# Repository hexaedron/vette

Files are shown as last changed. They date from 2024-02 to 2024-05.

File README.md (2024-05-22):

# vette

A diagnostic device to watch ECM parameters and errors from 1992 Chevy Corvette (LT1 engine) via ALDL interface.
Built with ch32v003 chip with sh1106 screen.

You will need [ch32v00fun](https://github.com/cnlohr/ch32v003fun/) and [fun_sh1106](https://github.com/hexaedron/fun_sh1106) to build it. I prefer using official WCH toolchain. If you prefer using vanilla risc-v GCC, then remove `#define WCH_FAST_INTERRUPT_ENABLED` from `cube_defs.h`.

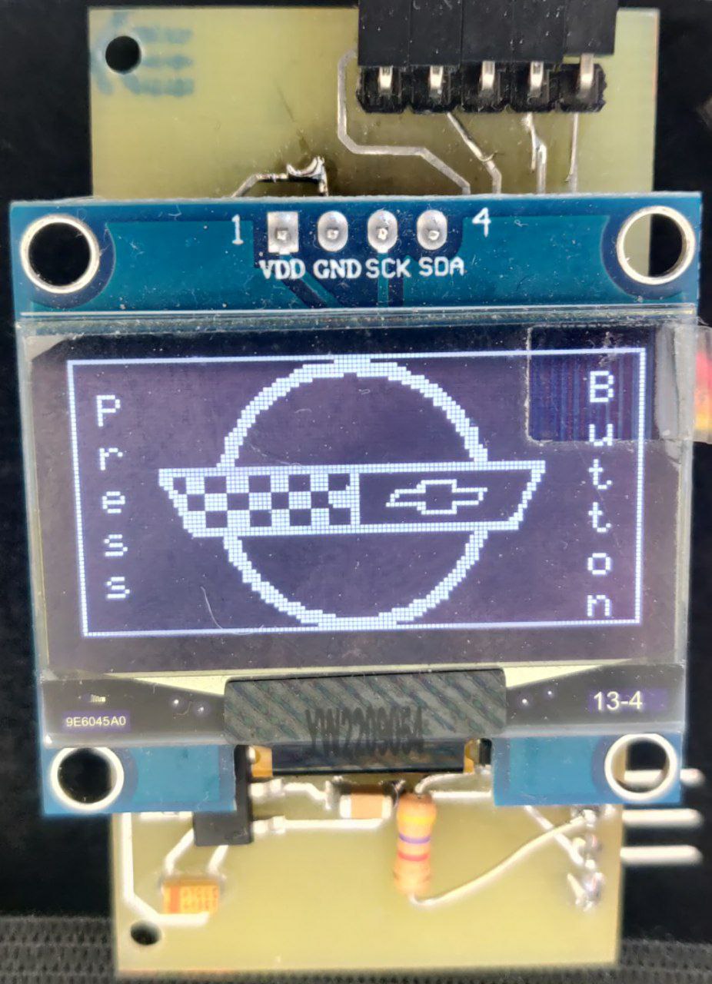
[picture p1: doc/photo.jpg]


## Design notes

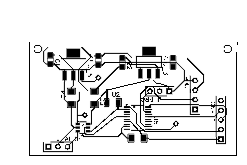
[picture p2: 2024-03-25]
PCB/PCB_PCB_CorvetteALDL_2024-03-25.png

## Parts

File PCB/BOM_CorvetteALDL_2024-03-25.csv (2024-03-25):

ID | Name | Designator | Footprint | Quantity | Manufacturer Part | Manufacturer | Supplier | Supplier Part | Price
1 | HDR-M-2.54_1x3 | J_PRG,J_ALDL | HDR-M-2.54_1X3 | 2 |  |  | LCSC | C180248 | 0.191
2 | HDR-M-2.54_1x5 | J_ENC | HDR-M-2.54_1X5 | 1 |  |  | LCSC | C358687 | 0.025
3 | 100nF | C3,C4,C5 | C1206 | 3 | C3216X7R2A104M160AA | TDK | LCSC | C3883507 | 0.477
4 | CH32V003F4P6 | U5 | TSSOP-20_L6.5-W4.4-P0.65-LS6.4-BL | 1 | CH32V003F4P6 | null | LCSC | C5187096 | 0.273
5 | LM1117GS-3.3 | U_3 | SOT-223-3_L6.5-W3.4-P2.30-LS7.0-BR | 1 | LM1117GS-3.3 | HTC | LCSC | C411821 | 0.154
6 | LM1117GS-5.0 | U_5 | SOT-223-3_L6.5-W3.4-P2.30-LS7.0-BR | 1 | LM1117GS-5.0 | HTC | LCSC | C465002 | 0.146
7 | 10uF | C1,C2,C6,C7 | CASE-A_3216 | 4 | TCA1A106M8R | ROHM(罗姆) | LCSC | C184153 | 0.048
8 | SN74LVC1T45DBVR | U1 | SOT-23-6_L2.9-W1.6-P0.95-LS2.8-BR | 1 | SN74LVC1T45DBVR | TI(德州仪器) | LCSC | C7843 | 0.19
9 | HDR-M-2.54_1x4 | J_1106 | HDR-M-2.54_1X4 | 1 |  |  | LCSC | C124378 | 0.043
10 | 4.7kΩ | U2,U3 | R1206 | 2 | FRC1206J472 TS | FOJAN(富捷) | LCSC | C2907499 | 0.002
10,Rotary encoder Arduino module (round),,,,,,,,
11,sh1106 screen,,,,,,,,

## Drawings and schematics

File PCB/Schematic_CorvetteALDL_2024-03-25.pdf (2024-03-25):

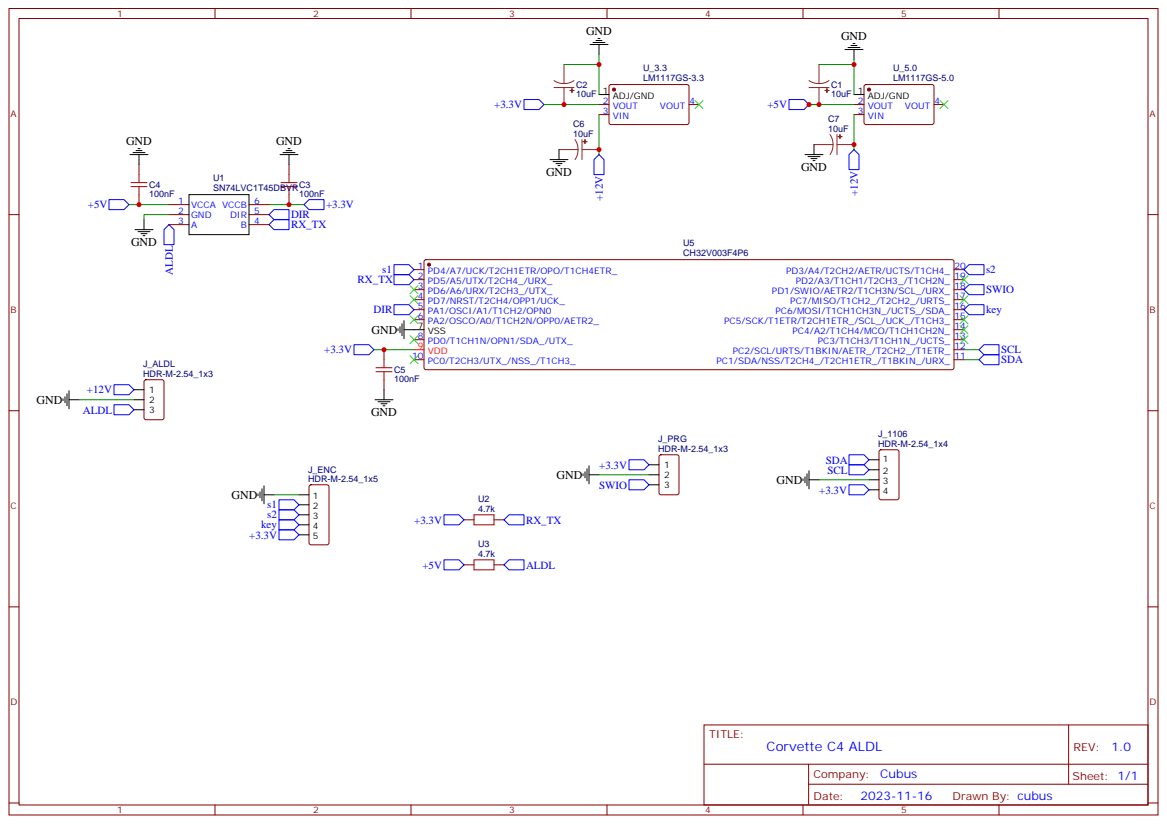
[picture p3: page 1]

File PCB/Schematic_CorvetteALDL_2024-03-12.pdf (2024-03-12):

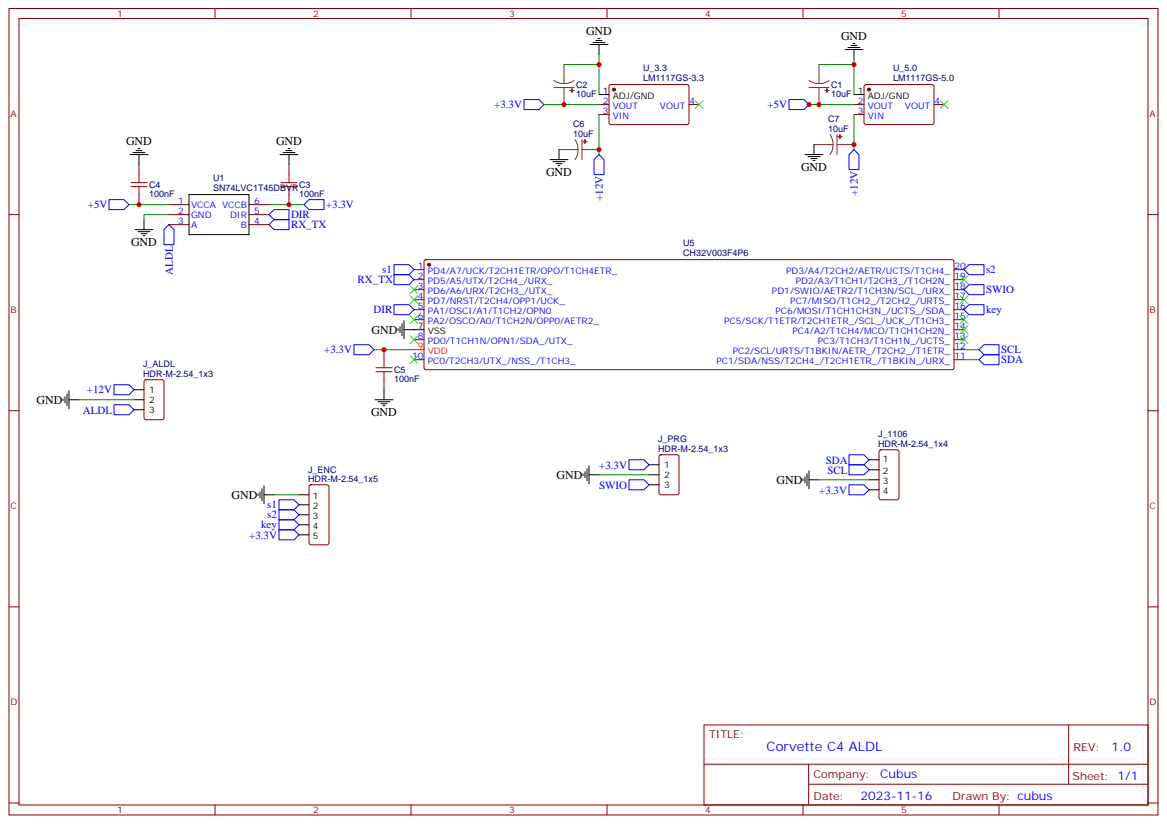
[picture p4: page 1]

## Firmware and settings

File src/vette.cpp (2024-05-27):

#include "ch32v003fun.h"
#include "include/cube_defs.h"

#include <stdbool.h>

#include "include/FSM.h"

extern const char vette_version[] = "1.0.1 beta";

// from system.cpp
void system_initSystick();
void system_initEXTI(uint32_t pin, bool risingEdge = true, bool fallingEdge = false);

int main()
{
	SystemInit();
	#ifdef WCH_FAST_INTERRUPT_ENABLED
		__set_INTSYSCR(0x3); // [Experimental] enable fast interrupt feature	
	#endif
	system_initSystick();

	// We use button on PC6, so we need to init it and turn on interrupt.	
	funGpioInitAll();
	funPinMode(PC6, GPIO_Speed_In | GPIO_CNF_IN_FLOATING);

	// We use PA1 as DIR pin for SN74LVC1T45DBVR
	// When it is low, we transmit,
	// when it is high, we receive
	funPinMode(PA1, GPIO_Speed_10MHz | GPIO_CNF_OUT_PP);

	fsm_init();
	
	while (true)
	{		
		fsm_update();
	}
}

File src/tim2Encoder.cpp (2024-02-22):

#include "include/tim2Encoder.h"

tim2Encoder::tim2Encoder(const uint32_t remapMode = AFIO_PCFR1_TIM2_REMAP_NOREMAP)
{
    this->init(remapMode);
    this->count      = TIM2->CNT >> 2;
    this->last_count = TIM2->CNT >> 2;
}

void tim2Encoder::init(const uint32_t remapMode = AFIO_PCFR1_TIM2_REMAP_NOREMAP)
{
    // Enable TIM2 and AFIO *very important!*
	RCC->APB2PCENR |= RCC_APB2Periph_AFIO;
	RCC->APB1PCENR |= RCC_APB1Periph_TIM2;

	AFIO->PCFR1 |= remapMode; //set remap mode 

	switch (remapMode) // We need to configure pins according to remap method 
	{
		case AFIO_PCFR1_TIM2_REMAP_NOREMAP:

			RCC->APB2PCENR |= RCC_APB2Periph_GPIOD;
			
			// PD4 is T2CH1_, Input w/ Pullup/down
			GPIOD->CFGLR &= ~(0xf<<(4*4)); //clear old values
			GPIOD->CFGLR |= (GPIO_CNF_IN_PUPD)<<(4*4); //set new ones
			//1 = pull-up, 0 = pull-down
			GPIOD->OUTDR |= 1<<4;

			// PD3 is T2CH2_, Input w/ Pullup/down
			GPIOD->CFGLR &= ~(0xf<<(4*3)); //clear values
			GPIOD->CFGLR |= (GPIO_CNF_IN_PUPD)<<(4*3); //set new ones
			//1 = pull-up, 0 = pull-down
			GPIOD->OUTDR |= 1<<3;

		break;

		case AFIO_PCFR1_TIM2_REMAP_PARTIALREMAP1:

			RCC->APB2PCENR |= RCC_APB2Periph_GPIOC;

			// PC5 is T2CH1_, Input w/ Pullup/down
			GPIOC->CFGLR &= ~(0xf<<(4*5)); //clear old values
			GPIOC->CFGLR |= (GPIO_CNF_IN_PUPD)<<(4*5); //set new ones
			//1 = pull-up, 0 = pull-down
			GPIOC->OUTDR |= 1<<5;

			// PC2 is T2CH2_, Input w/ Pullup/down
			GPIOC->CFGLR &= ~(0xf<<(4*2)); //clear values
			GPIOC->CFGLR |= (GPIO_CNF_IN_PUPD)<<(4*2); //set new ones
			//1 = pull-up, 0 = pull-down
			GPIOC->OUTDR |= 1<<2;
		break;

		case AFIO_PCFR1_TIM2_REMAP_PARTIALREMAP2:

			RCC->APB2PCENR |= RCC_APB2Periph_GPIOC | RCC_APB2Periph_GPIOD;

			// PC1 is T2CH1_, Input w/ Pullup/down
			GPIOC->CFGLR &= ~(0xf<<(4*1)); //clear old values
			GPIOC->CFGLR |= (GPIO_CNF_IN_PUPD)<<(4*1); //set new ones
			//1 = pull-up, 0 = pull-down
			GPIOC->OUTDR |= 1<<1;

			// PD3 is T2CH2_, Input w/ Pullup/down
			GPIOD->CFGLR &= ~(0xf<<(4*3)); //clear values
			GPIOD->CFGLR |= (GPIO_CNF_IN_PUPD)<<(4*3); //set new ones
			//1 = pull-up, 0 = pull-down
			GPIOD->OUTDR |= 1<<3;

		break;

		case AFIO_PCFR1_TIM2_REMAP_FULLREMAP:
			
			RCC->APB2PCENR |= RCC_APB2Periph_GPIOC;
			
			// PC1 is T2CH1_, Input w/ Pullup/down
			GPIOC->CFGLR &= ~(0xf<<(4*1)); //clear old values
			GPIOC->CFGLR |= (GPIO_CNF_IN_PUPD)<<(4*1); //set new ones
			//1 = pull-up, 0 = pull-down
			GPIOC->OUTDR |= 1<<1;

			// PC7 is T2CH2_, Input w/ Pullup/down
			GPIOC->CFGLR &= ~(0xf<<(4*7)); //clear values
			GPIOC->CFGLR |= (GPIO_CNF_IN_PUPD)<<(4*7); //set new ones
			//1 = pull-up, 0 = pull-down
			GPIOC->OUTDR |= 1<<7;

		break;
		
		default:
		break;
	}
	
	
	// Reset TIM2 to init all regs
	RCC->APB1PRSTR |= RCC_APB1Periph_TIM2;
	RCC->APB1PRSTR &= ~RCC_APB1Periph_TIM2;
	
	// set TIM2 clock prescaler If you want to reduce the resolution of the encoder
	//TIM2->PSC = 0x0000;

	// set a automatic reload if you want the counter to wrap earlier than 0xffff
	//TIM2->ATRLR = 0xffff;

	// SMCFGR: set encoder mode SMS=011b
	TIM2->SMCFGR |= TIM_EncoderMode_TI12;

	// initialize timer
	TIM2->SWEVGR |= TIM_UG;

	// set count to about mid-scale to avoid wrap-around
	TIM2->CNT = 0x8fff;

	// Enable TIM2
	TIM2->CTLR1 |= TIM_CEN;
}

int32_t tim2Encoder::getDelta(void)
{
    this->count = TIM2->CNT >> 2;
    int32_t tmp = (int32_t)this->count - this->last_count;
    this->last_count = this->count;
    return tmp;
}

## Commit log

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2024-01-05 UART работает и на приём, и на передачу!!!
2024-01-06 Добавил UART::beginHD. Надо обязательно проверить.
2024-01-06 Добавил описание датастрима ABS
2024-01-06 Добавил getABSMessage Поправил UART hald duplex
2024-01-07 Наконец заработал UART::beginHD, чему я рад вполне. Также добавил flush() и peek() в UART
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2024-01-08 Добавил команды ALDL сразу с чексуммами.
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2024-01-09 Добавил примитивный счёт времени с тиком 100мс, класс simpleTimer и вероятно устранил проблемы компиляции (-fno-forward-propagate )
2024-01-10 Добавил Ардуиноподобный millis(), но почему-то сейчас работает только 32 битный. Непонятно.
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2024-01-11 Пока остановился на uint32_t для счёта millis. Сил моих нет.
2024-01-14 С новым тулчейном заработало и -flto. Пока остался на 32бит millis(). Почему-то ни 64 бита, ни мои самописные классы не работают...
2024-01-15 Перенёс все неудачные попытки в каталог Attempts. Пока летим на uint32_t.
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2024-01-17 Добавил базовую поддержку энкодера.
2024-01-17 Заработало с классом от Алексея. Делов было в неверном атрибуте systick_handler
2024-01-17 Заработало на uint64_t!!! См. предыдущий коммит.
2024-01-18 Перешёл на симлинк, чтобы было удобнее обновлять ch32v003fun. Чуть причесал simpleTimer
2024-01-22 Подключил энкодер. В целом работает.
2024-01-23 Добавил атрибут __attribute__((section(".srodata"))) к обработчику systick. Это увеличивает расход RAM, но ускоряет работу, тем самым уменьшая погрешности счёта времени.
2024-01-23 Добавил поддержку кнопки через прерывания!
2024-01-24 Теперь tim2Encoder::init() правильно инициализирует пины в зависимости от режима ремапа.
2024-01-24 Предыдущий комми считать неверным.
2024-01-26 Быстрый и грязный драйвер для sh1106. Добавил коды ошибок для ALDL.
2024-01-27 Чуть причесал драйвер 1106
2024-01-29 Работаю над русским шрифтом. Сейчас более-менее работаетс UTF-8, надо переделывать под 1251
2024-01-29 Работаю над русским шрифтом. Кое-как раьотает с UTF-8, надо передалеть под 1251
2024-01-29 Коммит перед добавлением масштаба
2024-01-29 Полностью рабочий C-вариант. Надо сделать класс.
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2024-01-29 Ранняя, но рабочая версия с классом!
2024-01-29 Сделал всё лишнее приватным
2024-01-29 Теперь драйвер sh1106 обновляет только те страницы экрана, которые изменялись
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2024-01-30 Добавил промежуточные размеры шрифтов
2024-01-30 Добавил flipV() и flipH()
    [vette.cpp]
2024-01-30 Добавил инвалидацию маски обновления страниц
2024-02-03 Перенёс драйвер sh1106 в отдельный репозиторий
2024-02-08 Удалил лишнее и приступил к реализации FSM
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2024-02-08 Убрал весь отладочный код и перевёл на стейт-машину.
2024-02-08 tim2Encoder переехал в отдельный файл
2024-02-08 Перерабатываю глобальную видимость некоторых объектов
2024-02-08 Добавил лого при старте
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2024-02-09 Добавил enum с нумерами строк
2024-02-09 Добавил лого для экрана ошибок
2024-02-09 Переделал битмап, добавил каталог с картинками
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2024-02-13 Поменял работу дебаунсера - просто отключаю прерывания на BUTTON_DEBOUNCE_MS
2024-02-13 В модуле уже есть подтяжка. Чтобы её не ослаблять, внутреннюю отключим.
2024-02-13 Переделал btnPressed. Теперь при работе дебаунсера прерывания отключаются только на выбранном пине!
2024-02-13 Теперь system_initEXTI удобнее, она просто принимает номер пина
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2024-02-13 Добавил макросы для работы с номерами пинов
2024-02-13 Забыл HW_PIN_NUM в одном месте
2024-02-13 Добавил вид сверху для режима ABS
2024-02-13 Всё же 100мс лучше
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2024-02-14 gpio_pins.h теперь лишний - всё есть в ch32v003fun
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2024-02-14 Перевёл lineNumbers на массив, чтобы можео было юзать динамически в циклах и т.д.
2024-02-14 Начал делать взаимодействие с ECM
2024-02-15 Поправил быстрое сравнение pokeECMResponse
2024-02-15 Вынес часть кода в функции
2024-02-15 Уменьшил RX-буфер UART. Всё равно больше 63 символов там не будет. В перспективе можно ещё уменьшить.
2024-02-15 Добавил ещё один статус - fsm_connectECU_state()
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2024-02-15 Переименовал ECU ➡️ ECM
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2024-02-26 Чаще, чем раз в 500мс нет смысла опрашивать.
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2024-03-12 Добавил PCB
    [CorvetteALDL_Schematics_2024-03-12.schdoc, PCB_CorvetteALDL_2024-03-12.pcbdoc]
2024-03-12 BOM + Pick&Place
    [BOM_CorvetteALDL_2024-03-12.csv, PickAndPlace_PCB_CorvetteALDL_2024-03-12.csv]
2024-03-12 Docs. typos, BOM update
    [BOM_CorvetteALDL_2024-03-12.csv]
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2024-03-17 Делаю стиралку ошибок. Для этого пришлось сильно поменять работу с прерываниями от кнопки.
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2024-03-25 PCB update
    [BOM_CorvetteALDL_2024-03-12.csv, BOM_CorvetteALDL_2024-03-25.csv, CorvetteALDL_Schematics_2024-03-12.schdoc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]
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2024-05-11 Увеличил ожидание ответа от ECM. До этого он не успевал ответить.
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2024-05-16 Добавил отключаемый Silent Mode и добавил именование промежутков времени
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2024-05-16 Начал делать fixAndCheckABSData()
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2024-05-20 Нельзя делать delay_ms() в режиме записи в UART - могут возникать фантомные нули.
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2024-05-21 Перешёл от прерываний к опросу кнопки. Так даже удобнее.
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2024-05-23 Работает диагностики и ABS. Это последняя однорежимная версия.
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2024-05-27 Переделал работу с systcik в соответствии с https://github.com/cnlohr/ch32v003fun/wiki/Time
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
